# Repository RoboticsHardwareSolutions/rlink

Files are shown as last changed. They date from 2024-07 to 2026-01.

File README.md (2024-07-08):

# rlink

mcu programmer (st-link v2.1 or jlink)

[firmware.bin](firmware/firmware.bin) - the firmware for creating the st-link programmer. You can flash it to link using
STLinkReflash.

[jlink_stlink_firmware.bin](firmware/jlink_stlink_firmware.bin) - the firmware for creating the jlink-stlink. You must
change the serial number in the firmware to 0x0000F800. The value must be 0x2EXXXXXX.

## Documentation:
[all documentation files](doc/pcb/)<br>
[schematic](<doc/pcb/Schematic Prints.PDF>)<br>
[assembly drawings](<doc/pcb/Assembly Drawings.PDF>)<br>
[board options](doc/pcb/board_options.txt)

## Pinout and pcb image
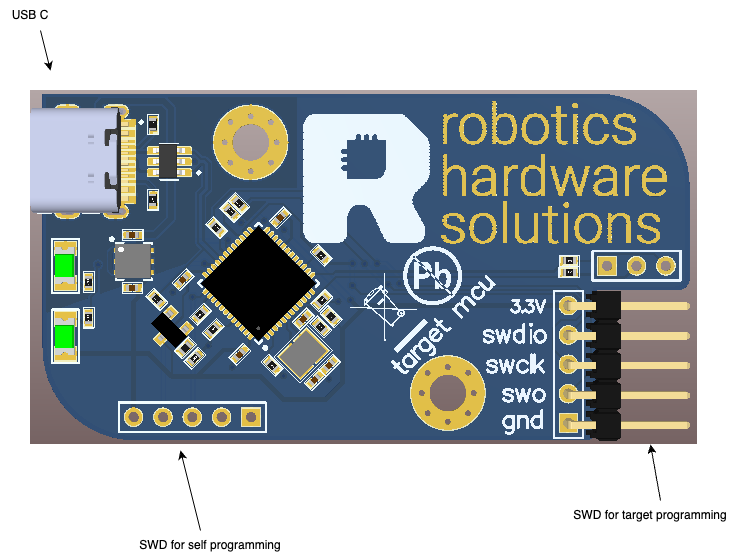
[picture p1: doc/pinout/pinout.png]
pinout
   
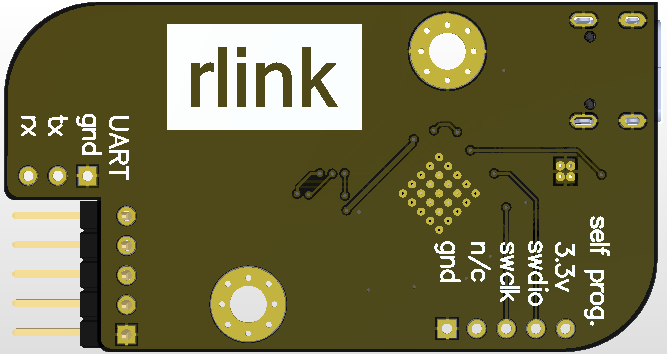
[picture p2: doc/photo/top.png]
  
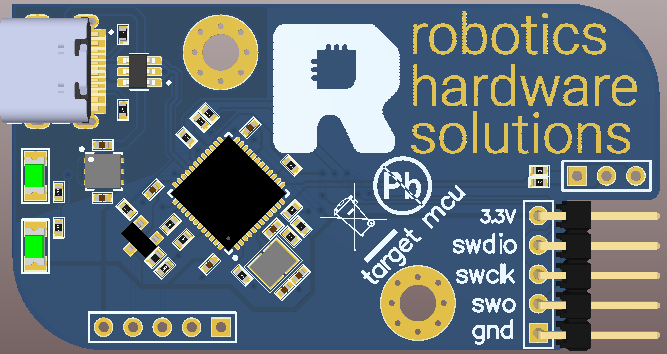
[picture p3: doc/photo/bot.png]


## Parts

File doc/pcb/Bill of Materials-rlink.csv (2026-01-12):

Description | Comment | Designator | Footprint | Part | Alternative Part | Quantity
Capacitor | 100nF 16V | C1, C2, C3, C6 | C_0402 | CC0402JRX7R6BB104 |  | 4
Capacitor | 10pF 16V | C4, C5 | C_0402 | CC0402GRNPO9BN100 |  | 2
Capacitor | 4.7uF 16V | C7 | C_0402 | CC0402KRX5R6BB475 |  | 1
Capacitor | 1uF 16V | C8 | C_0402 | CC0402KRX5R6BB105 |  | 1
Typical INFRARED GaAs LED |  | D1, D2 | LED_1206 | E6C1204QBAC1UDA |  | 2
Resistor | 10K | R1 | R_0402 | RC0402JR-0710KL |  | 1
Resistor | 100 | R2, R4, R5, R9 | R_0402 | RC0402FR-07100RL |  | 4
Resistor | 36K | R3 | R_0402 | RC0402JR-0736KL |  | 1
Resistor | 4.7K | R6, R7, R10 | R_0402 | RC0402JR-074K7L |  | 3
Resistor | 1.5K | R8 | R_0402 | RC0402JR-071K5L |  | 1
Resistor | 100K | R11, R12 | R_0402 | RC0402JR-07100KL |  | 2
Resistor | 22 | R13, R14, R15 | R_0402 | RC0402FR-0722RL |  | 3
Resistor | 5.1k | R16, R17 | R_0402 | RC0402JR-075K1L |  | 2
Header, 5-Pin | PLS2-5 | RLINK_TP1 | PLS-5-3D | MTSW-105-10-G-S-382-NA | 890-18-005-20-001101 / MTSW-105-10-F-S-355-NA | 1
NPN Bipolar Transistor | MMBT9013 | T1 | SOT23 | KTC9013S-H-RTK |  | 1
STM32 ARM-based 32-bit MCU Performance Line with 128 kB Flash, 20 kB Internal RAM, -40 to +85°C Temperature, 48-Pin VFQFPN, Tray | STM32F103CBU6 | U1 | STM-UFQFPN48_M | STM32F103CBU6 |  | 1
17V Clamp 5A (8/20Aµs) Ipp Tvs Diode Surface Mount SOT-23-6 | USBLC6-2SC6 | U2 | SOT95P280X145-6N | USBLC6-2SC6 |  | 1
LP38690, LP38692 1-A LDO CMOS Linear Regulators Stable with Ceramic Output Capacitors | LP38692-3.3V | U3 | WSON-6 | LP38692-3.3V |  | 1
USB Connectors 24 Receptacle 1 8.94*7.3mm RoHS | TYPE-C-31-M-12 | X1 | HRO_TYPE-C-31-M-12 | TYPE-C-31-M-12 |  | 1
NOT FITTED | NOT FITTED | X2 | NOT FITTED | NOT FITTED |  | 0
Crystal Oscillator | NX3225GD-8.000M | Y1 | NX3225GD | NX3225GD-8MHZ-STD-CRA-3 |  | 1
NOT FITTED | NOT FITTED | RLINK_SP1 | NOT FITTED | NOT FITTED |  | 0

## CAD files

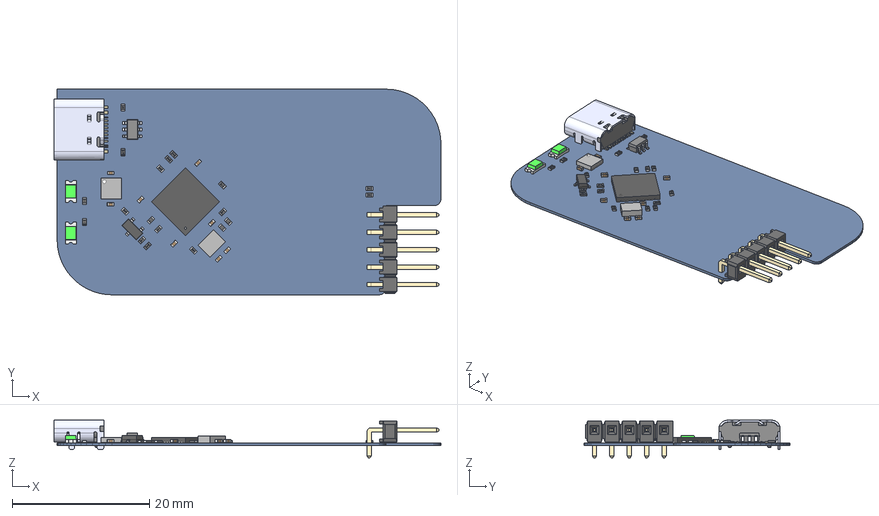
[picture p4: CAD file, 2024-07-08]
doc/drawing/rlink_pcb.step
56.5 x 30.0 x 5.51 mm
User Library-0402R x 19
User Library-WSON-6
User Library-QFN48_7x7
TYPE-C-31-M-12
User Library-cap_0402 x 8
SOT-23
User Library-LED 1206 BLUE x 2
Extruded
User Library-5 x Samtec-Header RightAngle 2_54mm Pitch

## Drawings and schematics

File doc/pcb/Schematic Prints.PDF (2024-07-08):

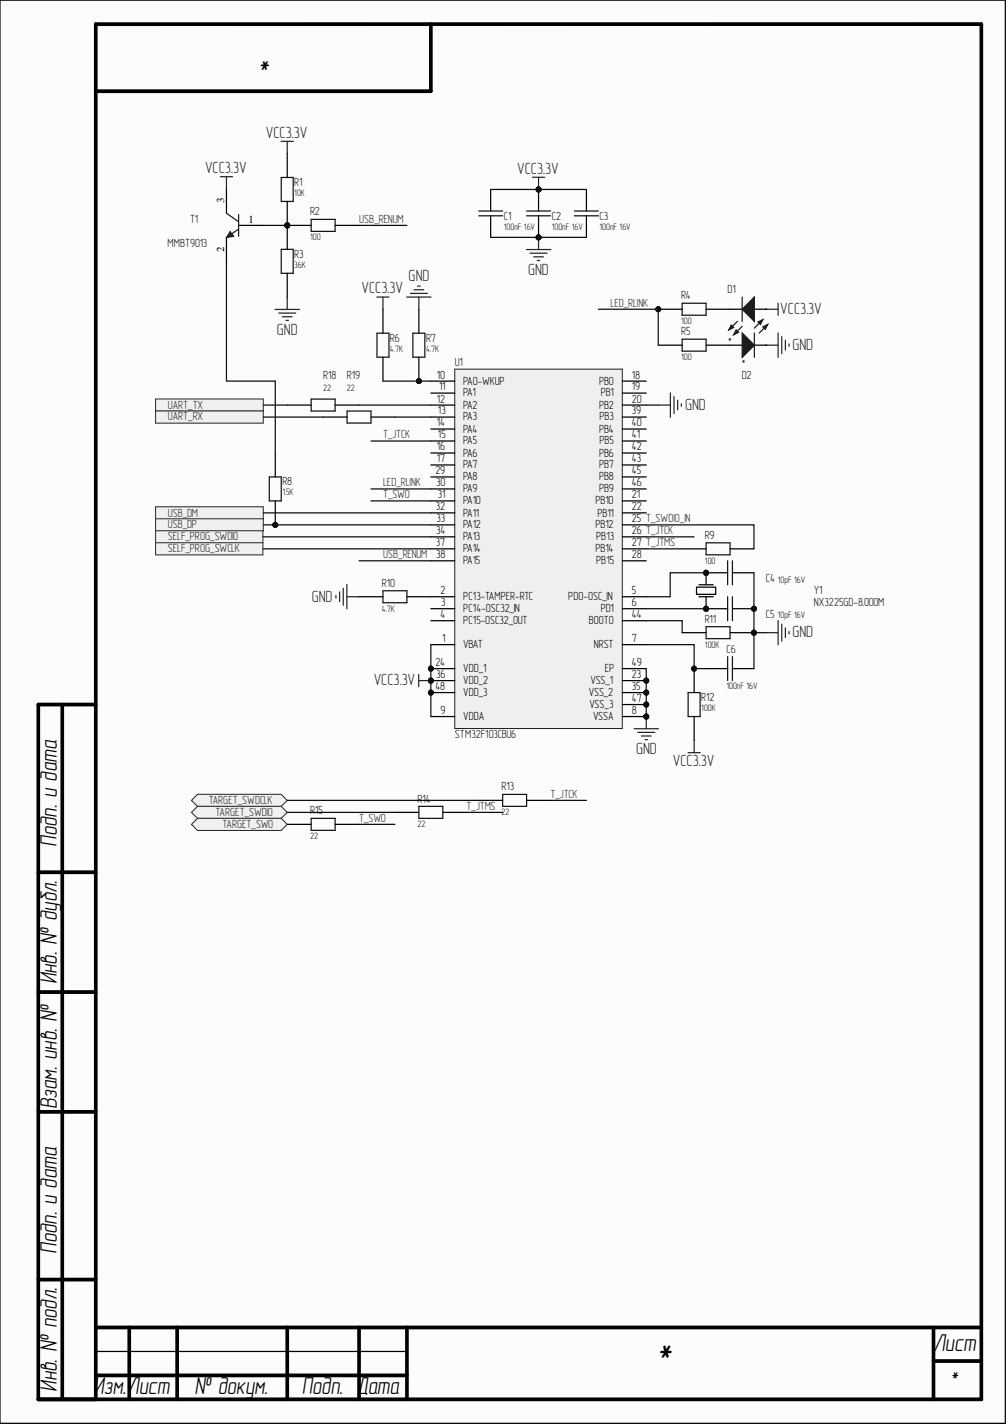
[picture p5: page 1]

UART_TX
UART_RX

PA3 13 | T_SWDIO_IN

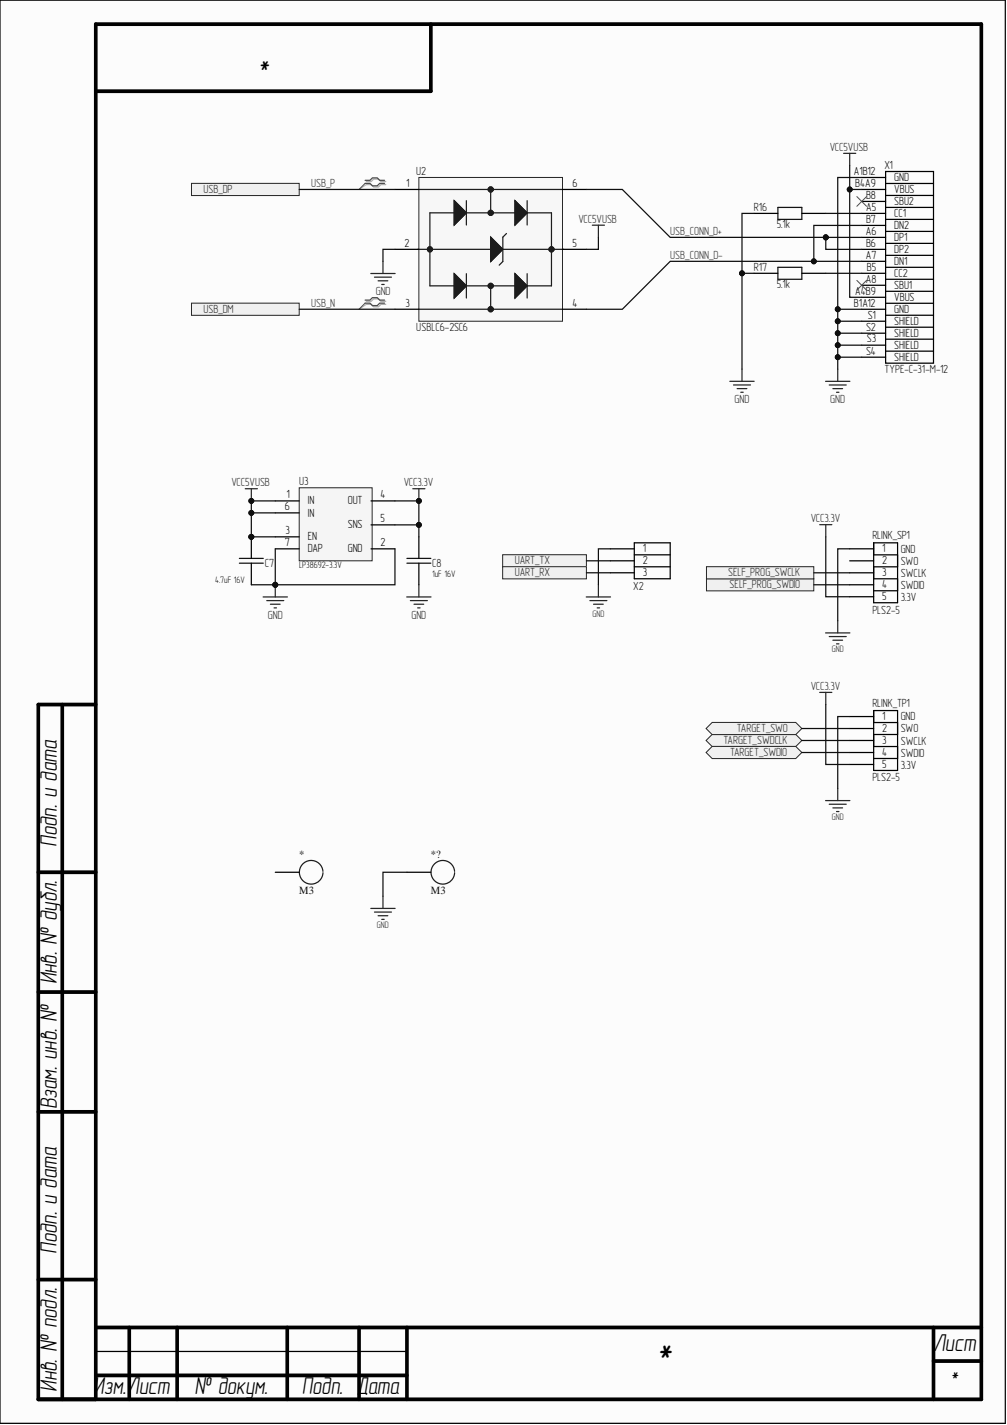
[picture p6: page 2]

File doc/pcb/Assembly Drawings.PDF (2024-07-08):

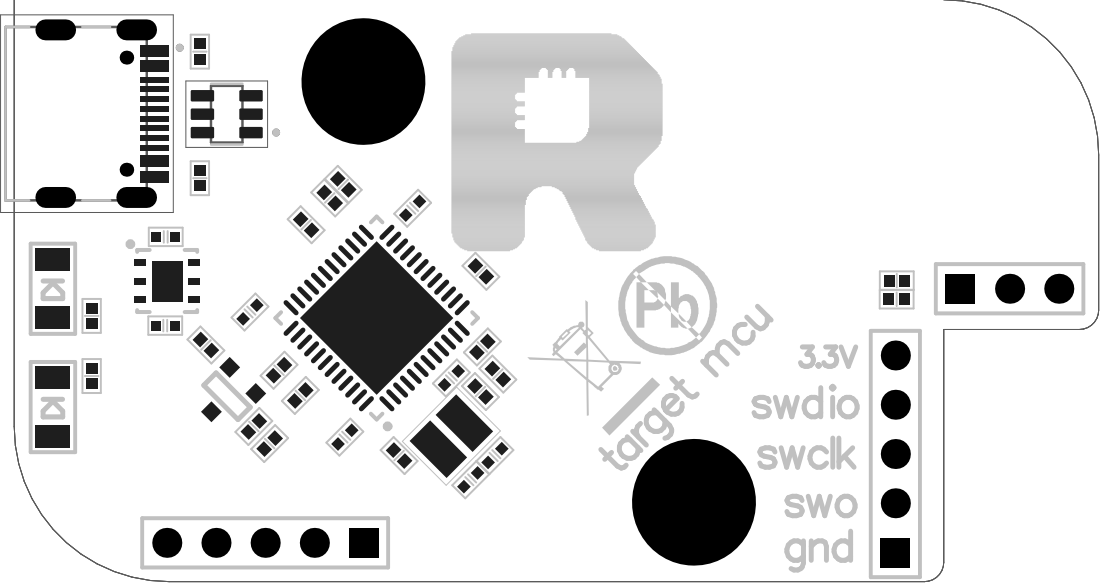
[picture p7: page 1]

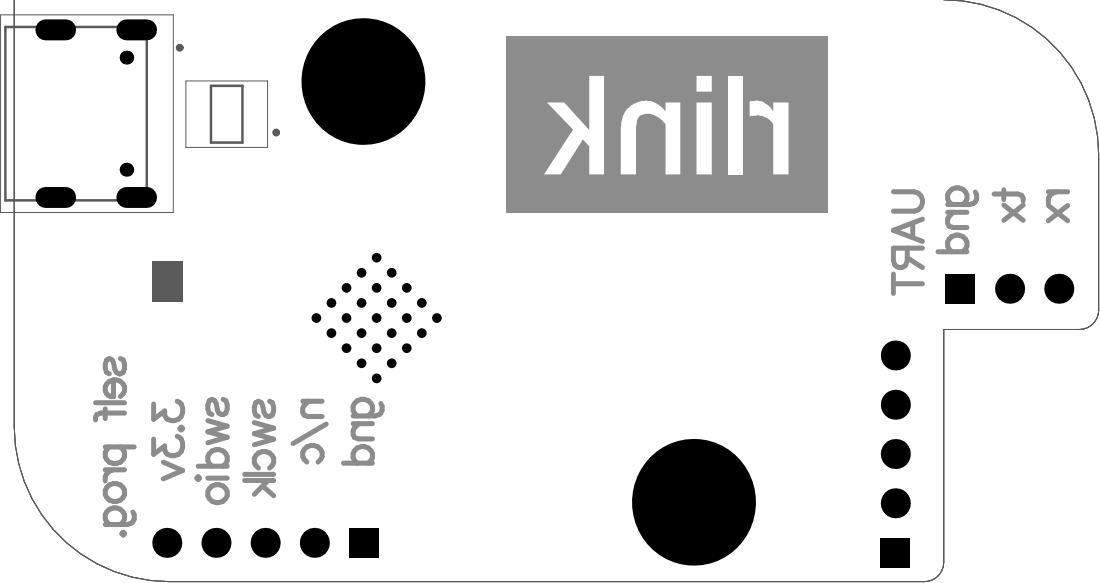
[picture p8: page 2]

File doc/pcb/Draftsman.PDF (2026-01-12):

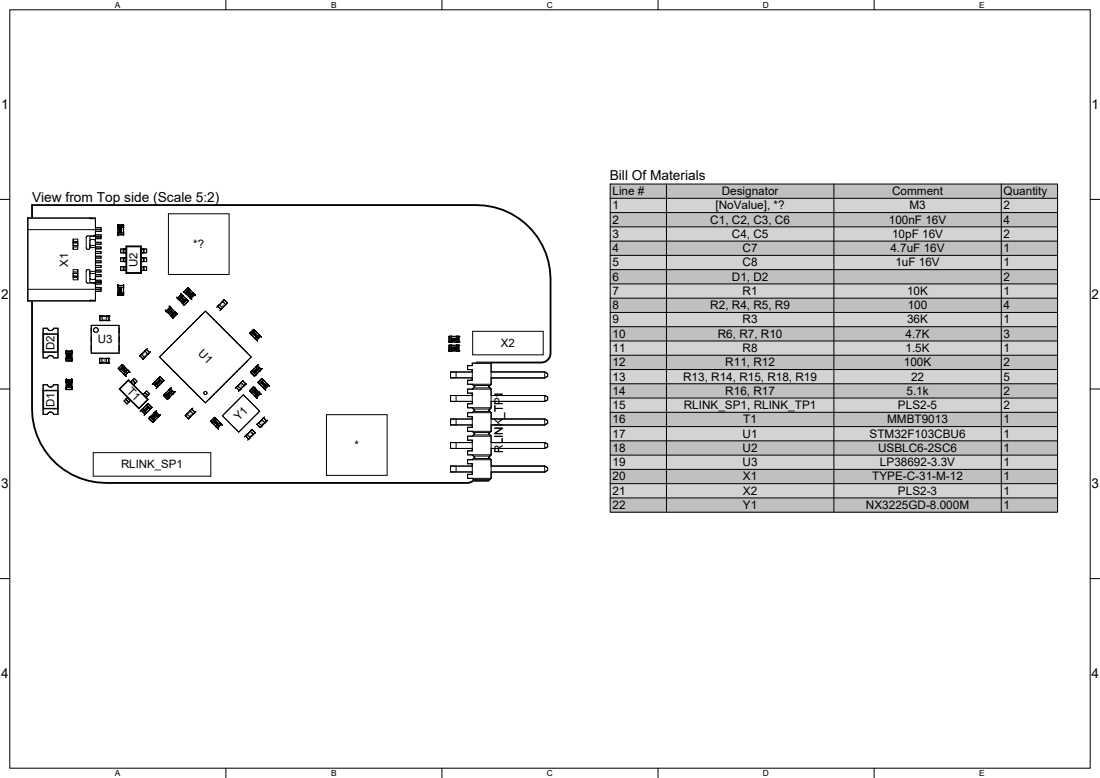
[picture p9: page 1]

View from Top side (Scale 5:2)

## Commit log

2026-01-03 add altguide check workflow for automated PCB checking
2026-01-12 Fixed some CI errors
    [Bill of Materials-rlink.csv, rlink.prjpcb]
2026-01-13 Fixed P&P file
    [Pick Place for rlink_pcb.csv]
